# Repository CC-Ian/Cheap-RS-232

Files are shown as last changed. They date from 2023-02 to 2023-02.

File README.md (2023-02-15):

# A $1 USB RS-232 Adaptor

RS-232 serial. It's super common when interfacing with test and measure equipment and with microcontrollers. Sometimes, you want a lot of them though, so instead of buying them online, you're best off making them yourself. Plus, these are a little nicer than what you can find online, and a little worse.

It's smaller, lighter, and USB type C, but it lacks some features like RTS, DIR, or CTS pins. It just has the bare necessitites. RX, TX, GND, ad VCC. Plus, it looks slick.

I'd wanted to sell these, but it doesn't make sense. Make them yourself, or integrate this circuit into your own projects.

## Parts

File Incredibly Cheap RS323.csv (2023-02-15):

Item | Qty | Reference(s) | Value | MPN | LCSC | Unit Cost | Total
1 | 2 | C1, C2 | 100n | TCC0402X5R104M250AT | C359190 | 0.0008 | 0.0016
2 | 2 | C3, C4 | 1u | TCC0402X5R105K6R3AT | C380294 | 0.0015 | 0.003
3 | 1 | J1 | USB_C_Receptacle_USB2.0 | TYPE-C-31-M-12 | C165948 | 0.2213 | 0.2213
4 | 1 | J3 | UART | PZ254V-11-04P | C2691448 | 0.0198 | 0.0198
5 | 2 | R1, R2 | 5k1 | FRC0603J512 TS | C2907114 | 0.008 | 0.016
6 | 1 | SW1 | SW_Push_SPDT | SK-3296S-01-L1 | C319020 | 0.0493 | 0.0493
7 | 1 | U1 | CH340N | CH340N | C2977777 | 0.4869 | 0.4869
8 | 1 | U2 | ME6211C | ME6211C33R5G | C235316 | 0.0708 | 0.0708
9 | 1 | PCB | PCB | PCB | ----- | 0.0281666666666667 | 0.0281666666666667
 |  |  |  |  |  |  | 0.896866666666667

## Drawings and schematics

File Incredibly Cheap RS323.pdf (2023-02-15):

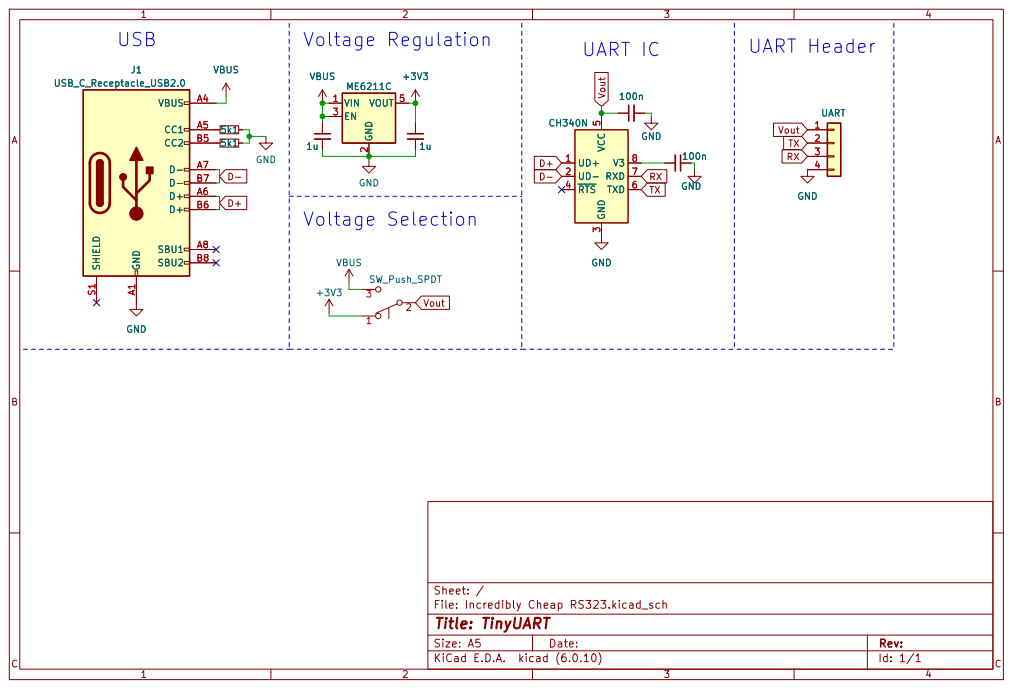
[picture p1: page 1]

File: Incredibly Cheap RS323.kicad_sch Sheet: / GND

5 TXD 6 RXD 7 V3 8 CH340N GND GND

5 TXD 6 RXD 7 V3 8 GND GND GND

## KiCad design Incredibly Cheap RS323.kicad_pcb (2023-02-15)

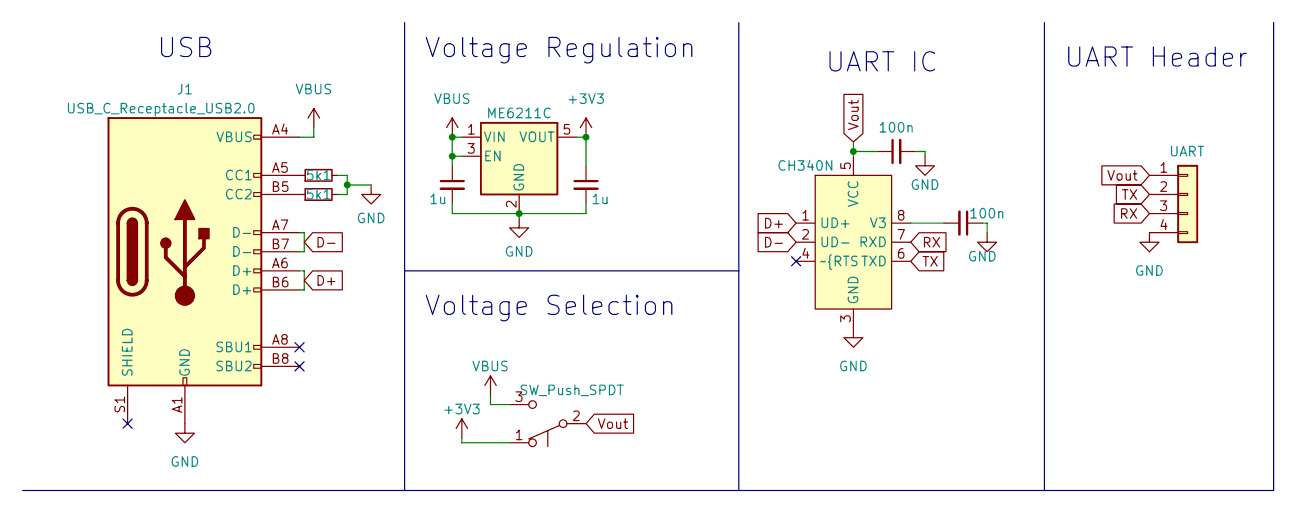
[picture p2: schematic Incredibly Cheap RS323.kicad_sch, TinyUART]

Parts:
C1, C2: 100n; C_0402_1005Metric
C3, C4: 1u; C_0402_1005Metric
J1: USB_C_Receptacle_USB2.0; USB_C_Receptacle_HRO_TYPE-C-31-M-12
J3: UART; PinHeader_1x04_P2.54mm_Vertical
R1, R2: 5k1; R_0603_1608Metric
SW1: SW_Push_SPDT; SW_SPDT_PCM12
U1: CH340N; SOP-8_3.9x4.9mm_P1.27mm
U2: ME6211C; SOT-353_SC-70-5

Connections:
+3V3: C4.1, SW1.1 (A), U2.5 (VOUT)
D+: J1.A6 (D+), J1.B6 (D+), U1.1 (UD+)
D-: J1.A7 (D-), J1.B7 (D-), U1.2 (UD-)
GND: C1.2, C2.1, C3.2, C4.2, J1.A1 (GND), J1.A12 (GND), J1.B1 (GND), J1.B12 (GND), J3.4, R1.2, R2.2, U1.3 (GND), U2.2 (GND)
unnamed: C2.2, U1.8 (V3)
unnamed: J1.A5 (CC1), R1.1
unnamed: J1.B5 (CC2), R2.1
RX: J3.3, U1.7 (RXD)
TX: J3.2, U1.6 (TXD)
VBUS: C3.1, J1.A4 (VBUS), J1.A9 (VBUS), J1.B4 (VBUS), J1.B9 (VBUS), SW1.3 (C), U2.1 (VIN), U2.3 (EN)
Vout: C1.1, J3.1, SW1.2 (B), U1.5 (VCC)

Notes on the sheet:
UART IC
Voltage Selection
UART Header
Voltage Regulation
USB

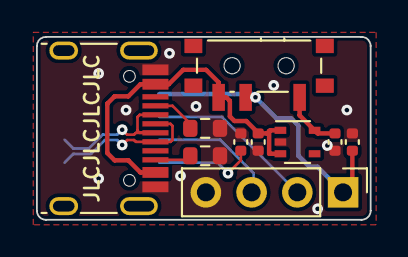
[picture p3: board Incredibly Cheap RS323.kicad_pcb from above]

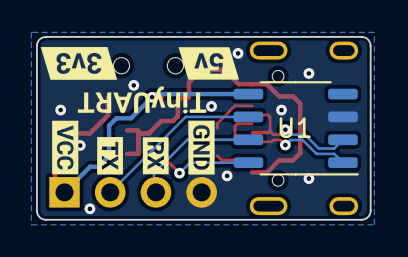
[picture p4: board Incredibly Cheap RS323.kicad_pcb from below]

Board: 2 copper layers, 18.5 x 10.2 mm, 18 parts (8 on the bottom side), 11 nets.

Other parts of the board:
kibuzzard-63CD506C: G***; kibuzzard-63CD506C
kibuzzard-63CD525C: G***; kibuzzard-63CD525C
kibuzzard-63CD526B: G***; kibuzzard-63CD526B
kibuzzard-63CD529F: G***; kibuzzard-63CD529F
kibuzzard-63CD5015: G***; kibuzzard-63CD5015
kibuzzard-63CD5248: G***; kibuzzard-63CD5248
kibuzzard-63CD5252: G***; kibuzzard-63CD5252
